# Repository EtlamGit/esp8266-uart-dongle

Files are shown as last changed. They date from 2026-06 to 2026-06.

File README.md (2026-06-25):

# esp8266-uart-dongle

A project for an esp8266 dongle for various IoT projects using UART.

Several manufacturers of home devices like air condition use a modified USB
connector as so called Wifi-Module to bring the devices into the manufacurer
cloud. These dongles can be replaced by this project to control your device
in your own cloud.

This project is inspired by https://github.com/dudanov/iot-uni-dongle

As there are no KiCad project files available, I had to rebuild it from scratch.

Other similar projects are:
* https://github.com/ezcGman/mideahvac-dongle

## Main goals

Stay the same as in the original project from Dudanov:

* using popular Wi-Fi module [ESP12-F](https://docs.ai-thinker.com/_media/esp8266/docs/esp-12f_product_specification_en.pdf) based on ESP8266 SoC
* unified design for all types of home devices from different manufacturers
* use of various connectors with a pitch of 2.54 mm and USB
* possibility of swapping the middle signal TX/RX contacts
* IR transmission and receiving via one wire connected to TSOP output
* very small design: PCB size 24.75 x 19 mm

I extended this with my own ideas:

* use only components in JLCPCB Basic or Promotional library
* use AMS1117 LDO
* use 0805 SMD components to allow hand soldering
* add reset pull-up and reset button
* add 100nF capacitor for ESP supply

## SMT assembly at JLCPCB

The [gerber](gerber) directory contains the files necessary for manufacturing
and assembling the board at the [JLCPCB](https://jlcpcb.com) factory.

You may get a warning notice that the USB connector is not present, but that
is intended as you have to solder that manually only when you need it.

Further steps are soldering the ESP module and selecting the TX/RX pin via
solder jumpers.

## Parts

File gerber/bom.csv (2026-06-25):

Reference | LCSC Part # | Qty | Value | DNP | Exclude from BOM | Exclude from Board | Footprint | Datasheet
C1,C2 | C45783 | 2 | 22µF |  |  |  | Capacitor_SMD:C_0805_2012Metric_Pad1.18x1.45mm_HandSolder
C3 | C49678 | 1 | 100n |  |  |  | Capacitor_SMD:C_0805_2012Metric
Q1,Q2,Q3,Q4 | C7420339 | 4 | BSS138 |  |  |  | Package_TO_SOT_SMD:SOT-23 | https://www.onsemi.com/pub/Collateral/BSS138-D.PDF
R1,R2,R3,R4,R5,R6,R7,R8,R9 | C17414 | 9 | 10k |  |  |  | Resistor_SMD:R_0805_2012Metric_Pad1.20x1.40mm_HandSolder
SW1 | C720477 | 1 | Reset |  |  |  | Button_Switch_SMD:SW_SPST_TS-1088-xR020
SW2 | C720477 | 1 | Flash |  |  |  | Button_Switch_SMD:SW_SPST_TS-1088-xR020
U1 | C6186 | 1 | AMS1117-3.3 |  |  |  | Package_TO_SOT_SMD:SOT-223-3_TabPin2 | http://www.advanced-monolithic.com/pdf/ds1117.pdf
U2 | C82891 | 1 | ESP-12F |  |  |  | RF_Module:ESP-12E | http://wiki.ai-thinker.com/_media/esp8266/esp8266_series_modules_user_manual_v1.1.pdf

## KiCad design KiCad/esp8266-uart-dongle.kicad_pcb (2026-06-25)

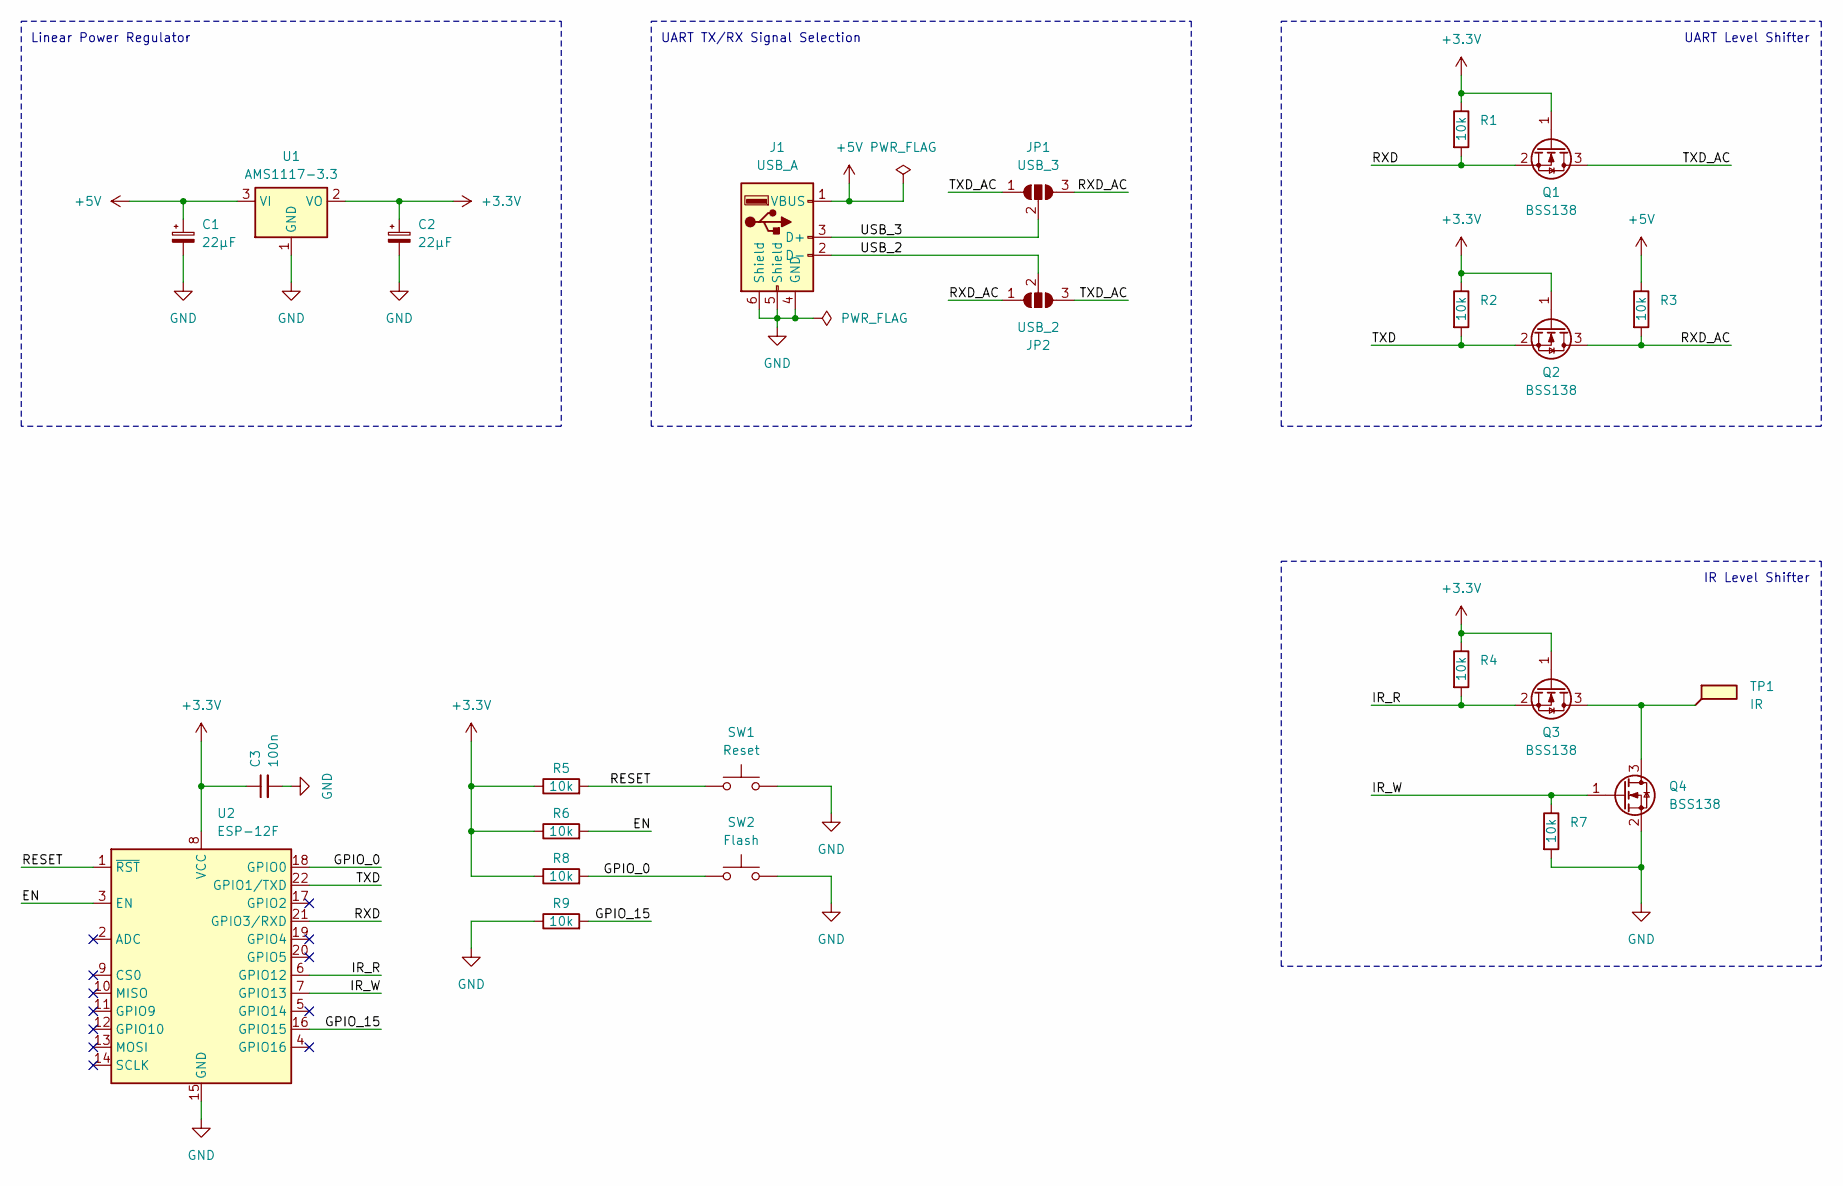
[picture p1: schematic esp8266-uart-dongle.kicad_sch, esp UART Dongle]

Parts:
C1, C2: 22µF; C_0805_2012Metric_Pad1.18x1.45mm_HandSolder; LCSC Part # C45783
C3: 100n; C_0805_2012Metric; LCSC Part # C49678
J1: USB_A; USB-A-TH_USB-ZL-109PWB
JP1: USB_3; SolderJumper-3_P1.3mm_Open_RoundedPad1.0x1.5mm_NumberLabels
JP2: USB_2; SolderJumper-3_P1.3mm_Open_RoundedPad1.0x1.5mm_NumberLabels
Q1, Q2, Q3, Q4: BSS138; SOT-23; LCSC Part # C7420339
R1, R2, R3, R4, R5, R6, R7, R8, R9: 10k; R_0805_2012Metric_Pad1.20x1.40mm_HandSolder; LCSC Part # C17414
SW1: Reset; SW_SPST_TS-1088-xR020; LCSC Part # C720477
SW2: Flash; SW_SPST_TS-1088-xR020; LCSC Part # C720477
TP1: IR; TestPoint_Keystone_5019_Miniature
U1: AMS1117-3.3; SOT-223-3_TabPin2; LCSC Part # C6186
U2: ESP-12F; ESP-12E; LCSC Part # C82891

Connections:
+3.3V: C2.1, C3.1, Q1.1 (G), Q2.1 (G), Q3.1 (G), R1.1, R2.1, R4.1, R5.1, R6.1, R8.1, U1.2 (VO), U2.8 (VCC)
+5V: C1.1, J1.1 (VBUS), R3.1, U1.3 (VI)
/EN: R6.2, U2.3 (EN)
/GPIO_0: R8.2, SW2.1, U2.18 (GPIO0)
/GPIO_15: R9.2, U2.16 (GPIO15)
/IR_R: Q3.2 (S), R4.2, U2.6 (GPIO12)
/IR_W: Q4.1 (G), R7.1, U2.7 (GPIO13)
/RESET: R5.2, SW1.1, U2.1 (~RST)
/RXD: Q1.2 (S), R1.2, U2.21 (GPIO3/RXD)
/RXD_AC: JP1.3 (B), JP2.1 (A), Q2.3 (D), R3.2
/TXD: Q2.2 (S), R2.2, U2.22 (GPIO1/TXD)
/TXD_AC: JP1.1 (A), JP2.3 (B), Q1.3 (D)
/USB_2: J1.2 (D-), JP2.2 (C)
/USB_3: J1.3 (D+), JP1.2 (C)
GND: C1.2, C2.2, C3.2, J1.4 (GND), J1.5 (Shield), J1.6 (Shield), Q4.2 (S), R7.2, R9.1, SW1.2, SW2.2, U1.1 (GND), U2.15 (GND)
unnamed: Q3.3 (D), Q4.3 (D), TP1.1 (1_1)

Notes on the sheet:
UART TX/RX Signal Selection
UART Level Shifter
IR Level Shifter
Linear Power Regulator

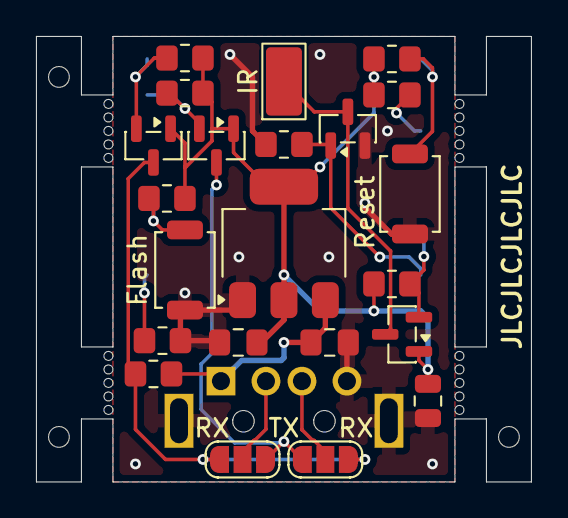
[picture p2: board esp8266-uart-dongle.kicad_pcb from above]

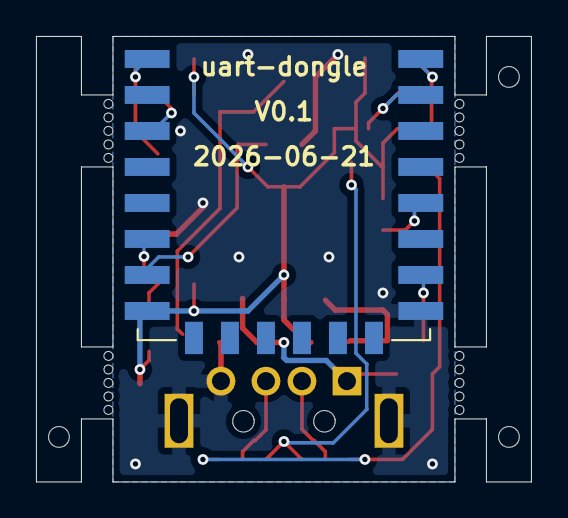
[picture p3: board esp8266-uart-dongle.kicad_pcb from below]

Board: 2 copper layers, 27.5 x 24.8 mm, 24 parts (2 on the bottom side), 16 nets.
